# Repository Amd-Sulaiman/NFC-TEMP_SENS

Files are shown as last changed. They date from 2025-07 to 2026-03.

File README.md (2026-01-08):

# NFC-TEMP_SENS
Gen 1 prototype of a contact-based temperature screening system using ESP32-C6 and NFC. Measures body temperature via Medical grade TMP117, stores data on an ST25DV64KC NFC tag, and supports smartphone tap-to-read + cloud sync for patient analytics.
# NFC-Based Smart Temperature Logger (Gen 1)

Gen-1 prototype: **ESP32-C6 Mini** + **TMP117** for contact body temperature, stores session data on **ST25DV64KC NFC tag** (tap with a smartphone to view) and can **send data to a server** for analysis. Each session records **12 readings in ~1 minute**, classifies **Normal / Fever / High Fever**, and saves a compact NDEF text payload to the NFC tag.

## ✨ Features
- Medical-grade temp sensor: **TMP117**
- NFC tag with dynamic memory: **ST25DV64KC**
- **ESP32-C6 Mini** (Wi-Fi + BT)
- **12 readings**/session (5s interval, ~60s total)
- Tap **smartphone → see temp + status**
- **HTTP POST** to server with session data
- **Patient ID** support (basic placeholder)

## 🧰 Hardware
| Part | Notes |
|---|---|
| ESP32-C6 Mini | 3.3V, I²C (SDA/SCL), Wi-Fi |
| TMP117 | I²C 0x48 (default), ±0.1°C typical |
| ST25DV64KC | NFC/RFID dynamic tag, I²C 0x53 |
| Finger contact | Ensure consistent placement/pressure |

## 📸 Prototype Gallery 

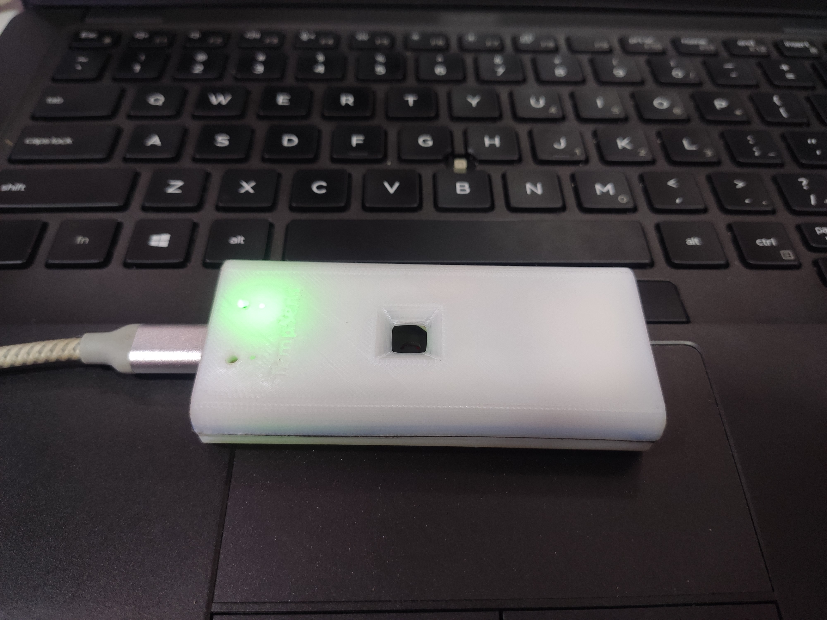
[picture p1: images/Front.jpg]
Prototype — Front

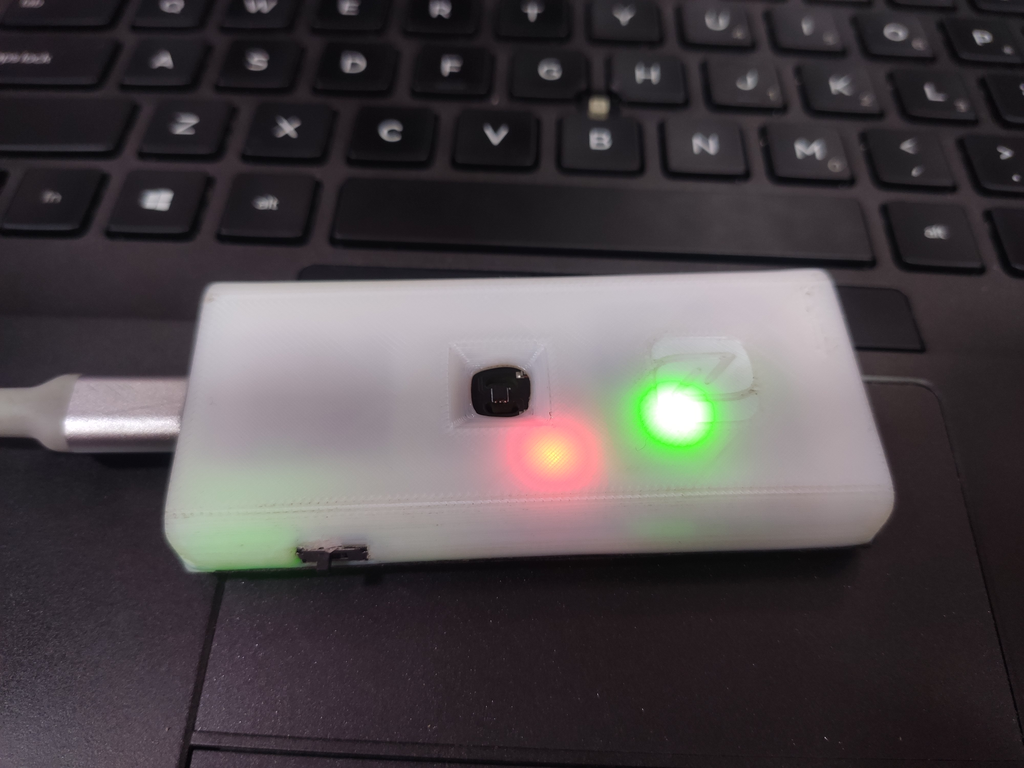
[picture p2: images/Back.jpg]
Prototype — Back

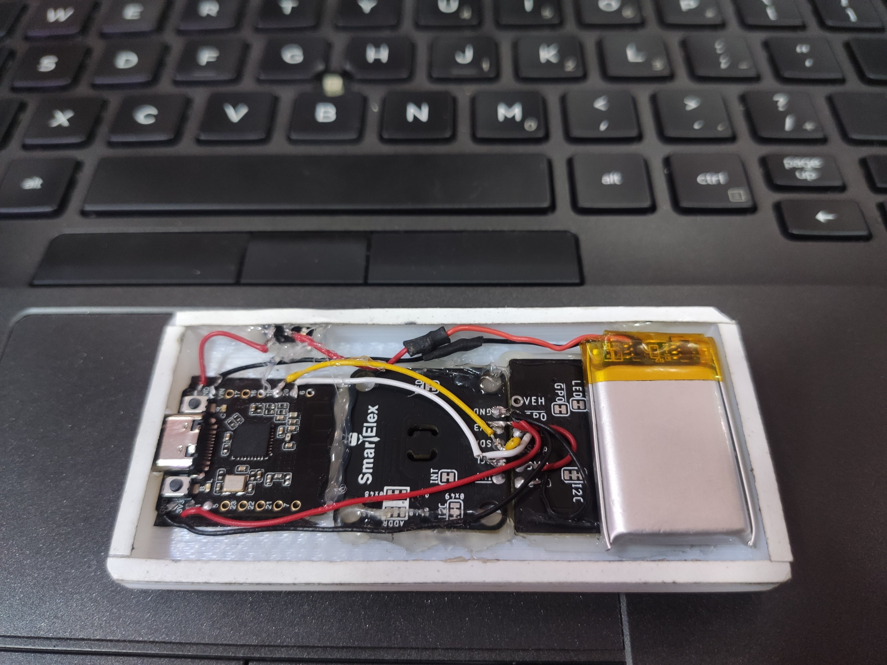
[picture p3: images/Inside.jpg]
Sensor Close-up


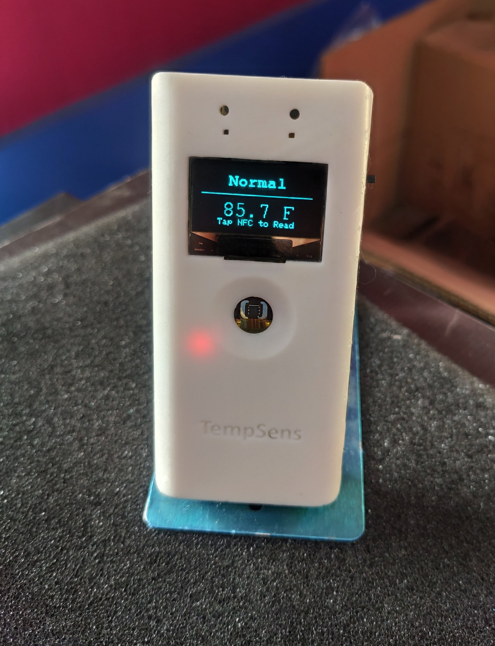
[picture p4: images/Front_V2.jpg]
Version2 — Front

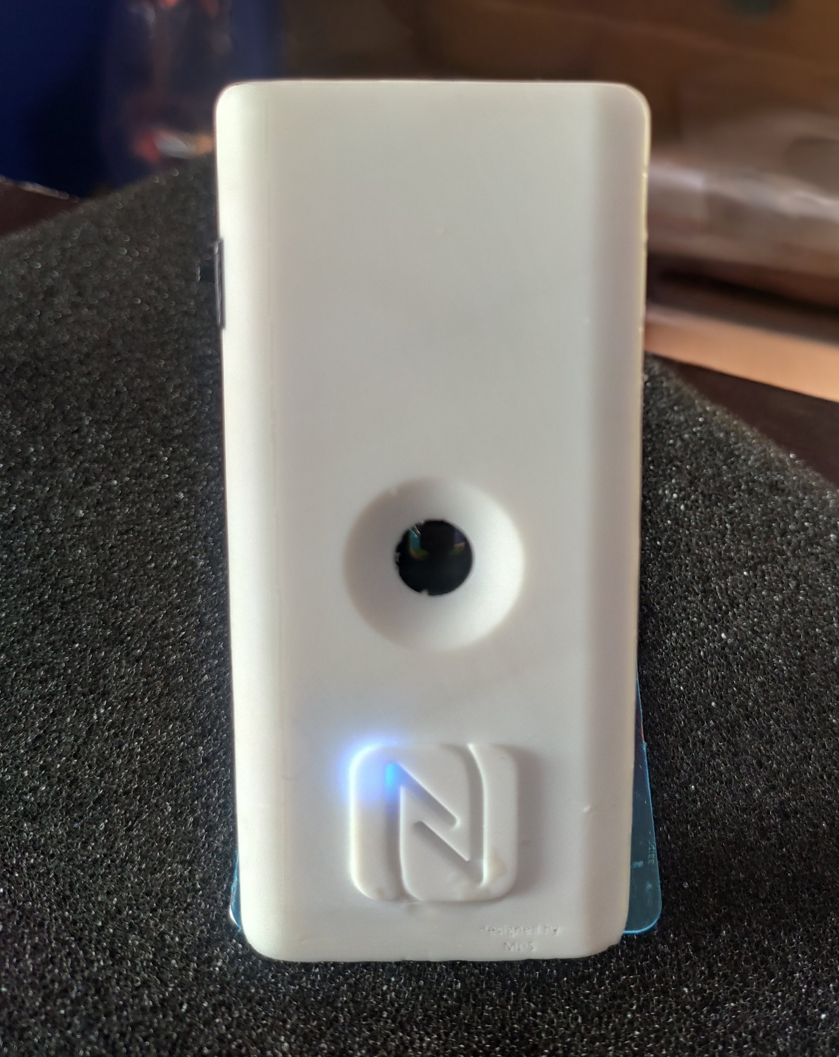
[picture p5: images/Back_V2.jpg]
Version2 — Back

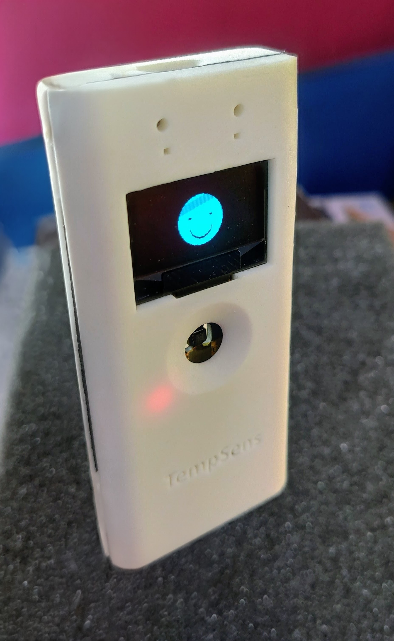
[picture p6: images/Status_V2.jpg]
Version2 — Status Page

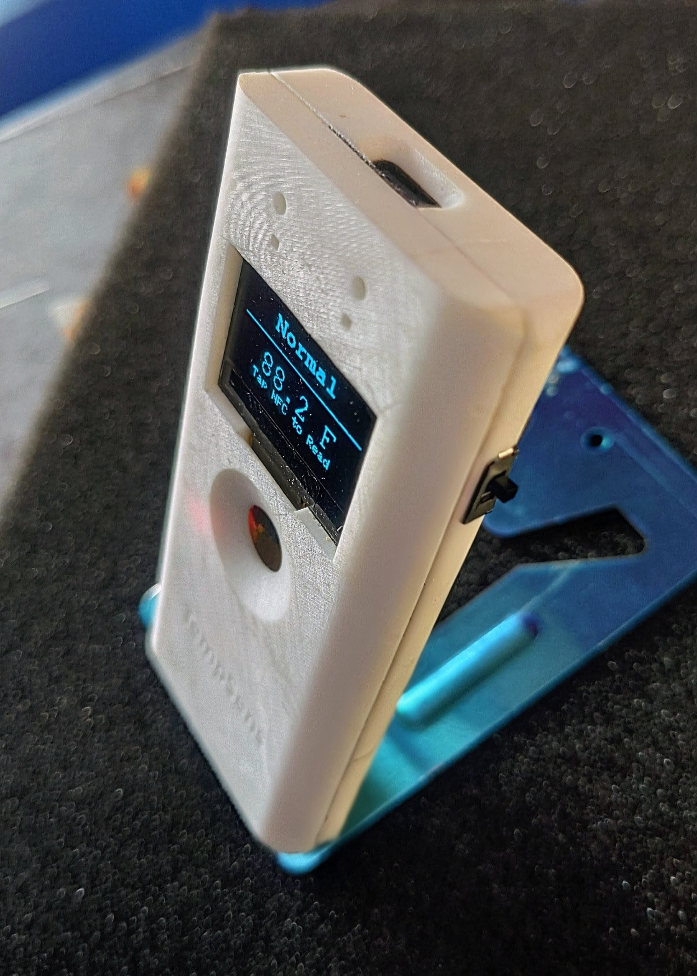
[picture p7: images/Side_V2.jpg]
Version2 — Side
.

## 🧱 3D Model & Enclosure

- [Enclosure Bottom (STL)](3D%20Model/SENS_enclosure_bottom.stl)
- [Enclosure top (STL)](3D%20Model/SENS_enclosure_top.stl)

## 🚦 Status thresholds (default)
- **Normal**: `< 37.5°C` (99.5°F)
- **Fever**: `≥ 37.5°C and < 38.9°C` (102.0°F)
- **High Fever**: `≥ 38.9°C`

> You can adjust these in `firmware/include/config.h`.

## 🔌 Firmware
- Arduino-style C++ (works in Arduino IDE or PlatformIO)
- I²C: TMP117 + ST25DV64KC
- Writes **NDEF Text** record: e.g. `T=37.8C; S=Fever; N=12; ts=2025-08-18T12:03:21Z; pid=abc123`

### Quick start (Arduino IDE)
1. Install **ESP32 boards** (Board Manager).
2. Open `firmware/src/main.cpp`.
3. Copy `firmware/include/secrets.h.example` → `secrets.h` and fill Wi-Fi + server.
4. Select your ESP32-C6 board, compile & upload.
5. Open Serial Monitor @ 115200.

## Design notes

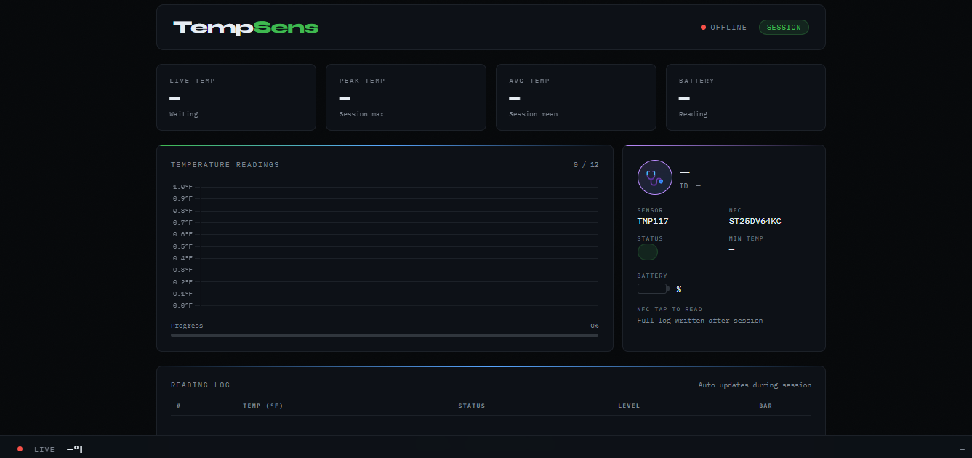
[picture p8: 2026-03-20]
images/dashboard.png

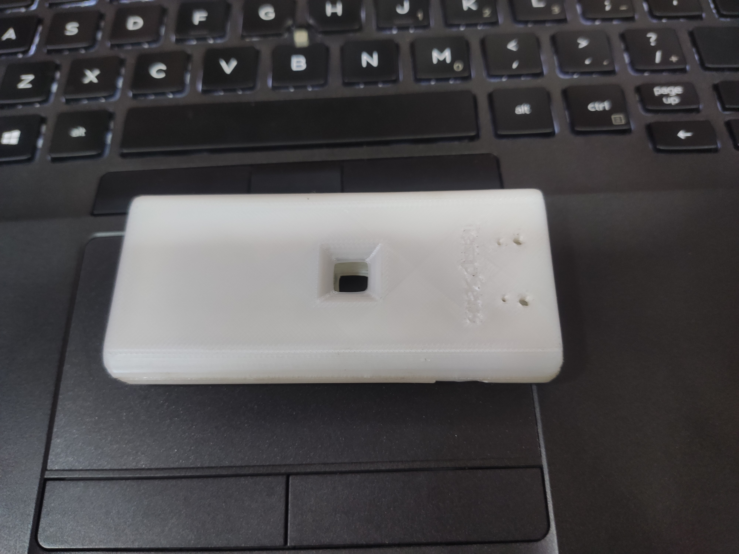
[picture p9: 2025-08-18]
images/Case.jpg

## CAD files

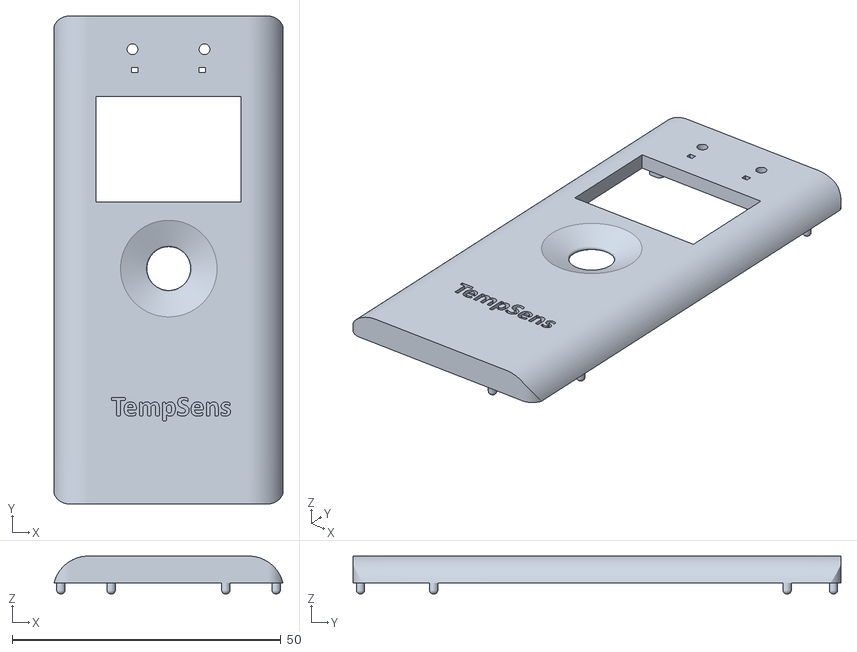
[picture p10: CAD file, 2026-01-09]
3D Model/Lid_V2.stl
42.6 x 90.8 x 7.05

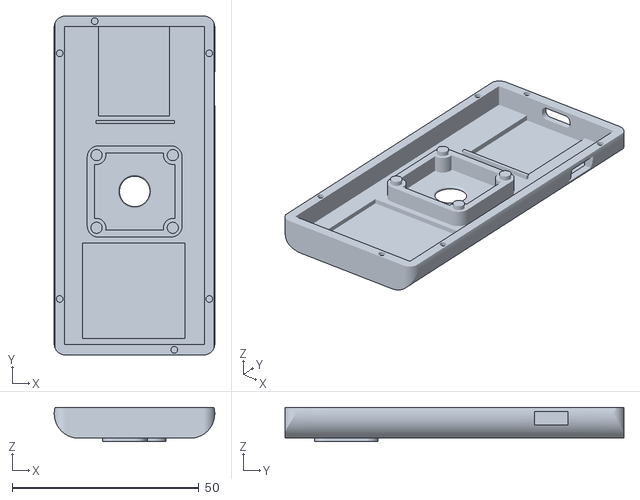
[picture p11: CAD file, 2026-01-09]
3D Model/Body_V2.stl
43.0 x 90.8 x 9.15

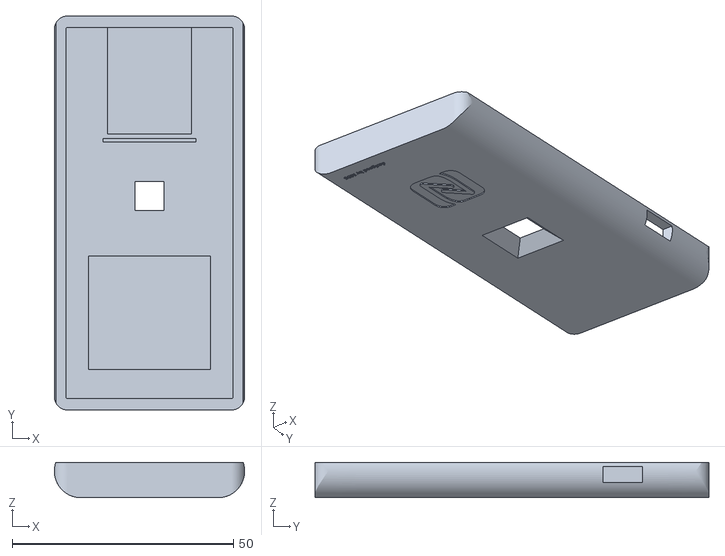
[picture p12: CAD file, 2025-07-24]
3D Model/SENS_enclosure_bottom.stl
43.0 x 89.0 x 8.00

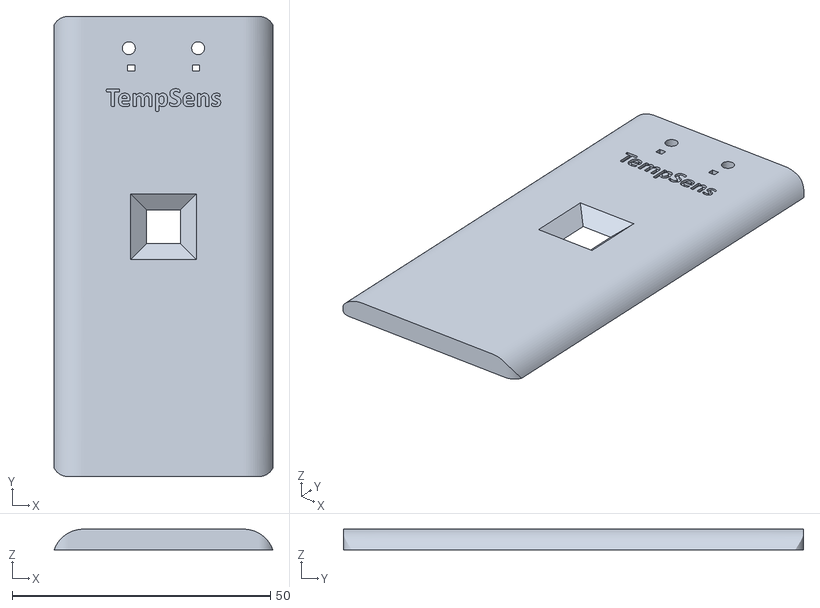
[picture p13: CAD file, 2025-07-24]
3D Model/SENS_enclosure_top.stl
42.3 x 89.0 x 4.00

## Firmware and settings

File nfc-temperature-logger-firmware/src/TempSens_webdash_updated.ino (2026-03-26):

/*
 * TempSens v5 — Cold Chain & Patient Monitor
 * ============================================
 * Hardware: ESP32, TMP117, ST25DV64KC (64Kbit = 8192 bytes), SSD1306 OLED
 *
 * ST25DV64KC MEMORY MAP:
 *   Total EEPROM : 8192 bytes
 *   Target usage : 70-80% = ~5734-6553 bytes
 *   NFC_LOG_MAX  : 5800 bytes (70.8%) — safe headroom
 *   CC File      : 8 bytes (managed by library)
 *   NDEF overhead: ~12 bytes per record
 *
 * KEY FEATURES:
 *   - NFC: meaningful alerts only (fever/high/sudden change/low) with \r\n
 *   - WiFi: continuous reading until power-off (no session limit)
 *   - WiFi: STA mode preferred; AP fallback; resets to STA-first on reboot
 *   - AP/STA SSID+Password configurable from web dashboard
 *   - OLED + WiFi update simultaneously (non-blocking millis() architecture)
 *   - Timestamps from browser JS injected via /api/sync
 *   - Anomaly detection: sustained high, sudden spike, sudden drop, sustained low
 *   - NFC writes top meaningful events only (not every reading)
 *   - Configurable: reading interval, NFC entry count, thresholds
 *
 * SETUP:
 *   1. Flash — open Serial at 115200
 *   2. On first boot with no saved WiFi: connects as AP "TempSens-Setup"
 *   3. Open 192.168.4.1 → Settings tab → enter your WiFi credentials → Save
 *   4. Device reboots into STA mode
 *   5. On subsequent boots: always tries STA first, AP only if STA fails after timeout
 */

#include <Wire.h>
#include <Adafruit_GFX.h>
#include <Adafruit_SSD1306.h>
#include <Fonts/FreeMono12pt7b.h>
#include <Fonts/FreeMonoBold9pt7b.h>
#include <SparkFun_ST25DV64KC_Arduino_Library.h>
#include <SparkFun_TMP117.h>
#include <WiFi.h>
#include <WebServer.h>
#include <ArduinoJson.h>
#include <Preferences.h>      // NVS — persist WiFi creds + config

// =====================================================
// HARDWARE
// =====================================================
#define SCREEN_WIDTH   128
#define SCREEN_HEIGHT   64
#define OLED_RESET      -1
#define BATTERY_PIN      1

Adafruit_SSD1306 display(SCREEN_WIDTH, SCREEN_HEIGHT, &Wire, OLED_RESET);
SFE_ST25DV64KC_NDEF tag;
TMP117 tempSensor;
WebServer server(80);
Preferences prefs;

// =====================================================
// NFC MEMORY BUDGET
// ST25DV64KC = 8192 bytes total EEPROM
// We target 70-80% = ~5734-6553 bytes
// NFC_LOG_MAX = 5800 bytes (70.8% of 8192)
// Each meaningful event line ≈ 60 bytes with \r\n
// So we can store ~90 meaningful events comfortably
// =====================================================
#define NFC_TOTAL_BYTES    8192
#define NFC_LOG_MAX        5800   // 70.8% of 8192 — target 70-80%
#define NFC_MAX_EVENTS      90    // max meaningful events stored on NFC

// =====================================================
// DEFAULT ADJUSTABLE PARAMETERS (saved to NVS, editable via web)
// =====================================================
#define DEFAULT_READING_INTERVAL_SEC  10
#define DEFAULT_NFC_STORE_EVERY_N      4   // store 1 in N normal readings on NFC
#define DEFAULT_TEMP_LOW              95.0  // F — below this = cold alert
#define DEFAULT_TEMP_ELEVATED         99.0  // F
#define DEFAULT_TEMP_FEVER           100.4  // F
#define DEFAULT_TEMP_HIGH_FEVER      102.4  // F
#define DEFAULT_SPIKE_THRESHOLD        1.5  // F change in one reading = spike
#define DEFAULT_NUM_NFC_READINGS       60   // max readings stored on NFC

// WiFi
#define AP_SSID_DEFAULT   "TempSens-Setup"
#define AP_PASSWORD       "tempsens123"
#define STA_CONNECT_TIMEOUT_MS  15000
#define WIFI_RETRY_INTERVAL_SEC    60

// OLED
#define OLED_TRANSITION_MS  400

// =====================================================
// RUNTIME CONFIG (loaded from NVS on boot)
// =====================================================
struct Config {
  char    staSSID[64];
  char    staPass[64];
  char    apSSID[32];
  char    patientName[32];
  char    patientID[16];
  char    monitorMode[16];  // "patient" or "coldchain"
  int     readingIntervalSec;
  int     nfcStoreEveryN;
  int     numNfcReadings;
  float   tempLow;
  float   tempElevated;
  float   tempFever;
  float   tempHighFever;
  float   spikeThreshold;
} cfg;

void loadConfig() {
  prefs.begin("tempsens", true);
  strlcpy(cfg.staSSID,          prefs.getString("ssid",    "").c_str(),          sizeof(cfg.staSSID));
  strlcpy(cfg.staPass,          prefs.getString("pass",    "").c_str(),          sizeof(cfg.staPass));
  strlcpy(cfg.apSSID,           prefs.getString("apssid",  AP_SSID_DEFAULT).c_str(), sizeof(cfg.apSSID));
  strlcpy(cfg.patientName,      prefs.getString("pname",   "Unknown").c_str(),   sizeof(cfg.patientName));
  strlcpy(cfg.patientID,        prefs.getString("pid",     "000").c_str(),       sizeof(cfg.patientID));
  strlcpy(cfg.monitorMode,      prefs.getString("mode",    "patient").c_str(),   sizeof(cfg.monitorMode));
  cfg.readingIntervalSec = prefs.getInt("interval",  DEFAULT_READING_INTERVAL_SEC);
  cfg.nfcStoreEveryN     = prefs.getInt("nfcevery",  DEFAULT_NFC_STORE_EVERY_N);
  cfg.numNfcReadings     = prefs.getInt("nfccount",  DEFAULT_NUM_NFC_READINGS);
  cfg.tempLow            = prefs.getFloat("tlow",    DEFAULT_TEMP_LOW);
  cfg.tempElevated       = prefs.getFloat("televated", DEFAULT_TEMP_ELEVATED);
  cfg.tempFever          = prefs.getFloat("tfever",  DEFAULT_TEMP_FEVER);
  cfg.tempHighFever      = prefs.getFloat("thigh",   DEFAULT_TEMP_HIGH_FEVER);
  cfg.spikeThreshold     = prefs.getFloat("tspike",  DEFAULT_SPIKE_THRESHOLD);
  prefs.end();
}

void saveConfig() {
  prefs.begin("tempsens", false);
  prefs.putString("ssid",      cfg.staSSID);
  prefs.putString("pass",      cfg.staPass);
  prefs.putString("apssid",    cfg.apSSID);
  prefs.putString("pname",     cfg.patientName);
  prefs.putString("pid",       cfg.patientID);
  prefs.putString("mode",      cfg.monitorMode);
  prefs.putInt("interval",     cfg.readingIntervalSec);
  prefs.putInt("nfcevery",     cfg.nfcStoreEveryN);
  prefs.putInt("nfccount",     cfg.numNfcReadings);
  prefs.putFloat("tlow",       cfg.tempLow);
  prefs.putFloat("televated",  cfg.tempElevated);
  prefs.putFloat("tfever",     cfg.tempFever);
  prefs.putFloat("thigh",      cfg.tempHighFever);
  prefs.putFloat("tspike",     cfg.spikeThreshold);
  prefs.end();
}

// =====================================================
// READING STORAGE (continuous — WiFi logs everything)
// Dynamic allocation capped at 2048 readings ~= plenty
// =====================================================
#define MAX_WIFI_READINGS  2048

struct Reading {
  float   tempF;
  uint32_t localMs;       // millis() at time of reading
  char    browserTime[24]; // "HH:MM:SS" from browser sync
  uint8_t flags;          // bitmask: 0x01=spike_up 0x02=spike_down 0x04=low 0x08=elevated 0x10=fever 0x20=high_fever
};

Reading  readings[MAX_WIFI_READINGS];
int      readingCount    = 0;
float    maxTemp         = -999.0;
float    minTemp         =  999.0;
float    latestTemp      =  98.6;
bool     sessionStarted  = false;

// NFC event log (only meaningful events)
struct NfcEvent {
  int     index;
  float   tempF;
  uint8_t flags;
  char    browserTime[24];
  float   change;
};
NfcEvent nfcEvents[NFC_MAX_EVENTS];
int      nfcEventCount   = 0;

// =====================================================
// WIFI / NETWORK STATE
// =====================================================
bool         wifiConnected    = false;
bool         apModeActive     = false;
unsigned long lastWifiRetryMs = 0;
unsigned long sessionStartMs  = 0;
unsigned long lastReadingMs   = 0;

// Browser time sync — offset between browser epoch and millis()
// browserEpochMs = millis() at moment of sync + browserTimeAtSync
bool          timeSynced        = false;
unsigned long syncMillis        = 0;
unsigned long long browserEpochAtSync = 0; // ms

// Current session status string
const char*  sessionStatus = "Waiting";

// =====================================================
// UTILITIES
// =====================================================

void printCentered(const char* text, int y, const GFXfont* font = NULL) {
  int16_t x1, y1; uint16_t w, h;
  if (font) display.setFont(font); else display.setFont();
  display.getTextBounds(text, 0, 0, &x1, &y1, &w, &h);
  int x = (SCREEN_WIDTH - w) / 2;
  if (font) display.setCursor(x, y + h); else display.setCursor(x, y);
  display.print(text);
}

float readBatteryVoltage() {
  long sum = 0;
  for (int i = 0; i < 16; i++) { sum += analogReadMilliVolts(BATTERY_PIN); delay(2); }
  return (sum / 16.0 * 2.0) / 1000.0;
}

int batteryPercentage(float v) {
  if (v >= 4.20) return 100;
  if (v <= 3.30) return 0;
  return constrain((int)(((v - 3.30) / (4.20 - 3.30)) * 100.0), 0, 100);
}

const char* classifyTemp(float f) {
  if (f < cfg.tempLow)         return "Low";
  if (f >= cfg.tempHighFever)  return "High Fever";
  if (f >= cfg.tempFever)      return "Fever";
  if (f >= cfg.tempElevated)   return "Elevated";
  return "Normal";
}

// Build flag bitmask for a reading
uint8_t buildFlags(float f, float prevF, bool isFirst) {
  uint8_t fl = 0;
  if (f < cfg.tempLow)                                  fl |= 0x04; // low
  if (f >= cfg.tempElevated && f < cfg.tempFever)       fl |= 0x08; // elevated
  if (f >= cfg.tempFever    && f < cfg.tempHighFever)   fl |= 0x10; // fever
  if (f >= cfg.tempHighFever)                           fl |= 0x20; // high fever
  if (!isFirst) {
    float diff = f - prevF;
    if (diff  >=  cfg.spikeThreshold) fl |= 0x01; // spike up
    if (diff  <= -cfg.spikeThreshold) fl |= 0x02; // spike down
  }
  return fl;
}

bool isMeaningful(uint8_t flags) {
  return flags != 0; // any flag = meaningful
}

// Get browser time string for a reading (uses sync offset)
void getBrowserTime(char* buf, size_t len, uint32_t readingMs) {
  if (!timeSynced) {
    snprintf(buf, len, "--:--:--");
    return;
  }
  unsigned long long epochMs = browserEpochAtSync + (readingMs - syncMillis);
  unsigned long epochSec = (unsigned long)(epochMs / 1000);
  int hh = (epochSec / 3600) % 24;
  int mm = (epochSec /   60) % 60;
  int ss =  epochSec         % 60;
  snprintf(buf, len, "%02d:%02d:%02d", hh, mm, ss);
}

// =====================================================
// OLED SCREENS
// =====================================================

void oledClear() {
  display.clearDisplay();
  display.display();
  delay(OLED_TRANSITION_MS);
}

void showWelcomeScreen() {
  oledClear();
  display.setTextColor(SSD1306_WHITE);
  printCentered("TempSens", 14, &FreeMono12pt7b);
  printCentered("v5", 36, NULL);
  display.drawRect(10, 48, 108, 6, SSD1306_WHITE);
  display.fillRect(12, 50, 104, 2, SSD1306_WHITE);
  display.display();
  delay(1500);
}

void showWiFiStatus(bool connected, const char* ip, bool isSTA) {
  oledClear();
  display.setFont(); display.setTextSize(1);
  if (connected && isSTA) {
    printCentered("WiFi Connected", 2, NULL);
    printCentered(ip, 20, NULL);
    printCentered("Open browser:", 36, NULL);
    printCentered(ip, 48, NULL);
  } else {
    printCentered("AP Mode", 2, NULL);
    printCentered(cfg.apSSID, 16, NULL);
    printCentered("pw:tempsens123", 30, NULL);
    printCentered("192.168.4.1", 46, NULL);
  }
  display.display();
  delay(3000);
}

void showReadingScreen(float fval, int idx, uint8_t flags) {
  // Temp value — top region
  display.fillRect(0, 0, 128, 30, SSD1306_BLACK);
  display.setFont(&FreeMono12pt7b);
  display.setTextColor(SSD1306_WHITE);
  char ts[14]; snprintf(ts, sizeof(ts), "%.1fF", fval);
  printCentered(ts, 2, &FreeMono12pt7b);

  // Status + flags
  display.setFont();
  display.fillRect(0, 32, 128, 9, SSD1306_BLACK);
  const char* cls = classifyTemp(fval);
  char statusLine[32];
  if      (flags & 0x01) snprintf(statusLine, sizeof(statusLine), "%s ^SPIKE", cls);
  else if (flags & 0x02) snprintf(statusLine, sizeof(statusLine), "%s vDROP",  cls);
  else                   snprintf(statusLine, sizeof(statusLine), "%s",         cls);
  printCentered(statusLine, 32, NULL);

  // Counter + elapsed
  display.fillRect(0, 44, 128, 8, SSD1306_BLACK);
  char lbl[28];
  int elapsed = (int)((millis() - sessionStartMs) / 1000);
  int em = elapsed / 60, es = elapsed % 60;
  snprintf(lbl, sizeof(lbl), "R%d | %02d:%02d", idx+1, em, es);
  printCentered(lbl, 44, NULL);

  // Alert bar if anomalous
  display.fillRect(0, 56, 128, 8, SSD1306_BLACK);
  if (flags) {
    display.fillRect(0, 56, 128, 8, SSD1306_WHITE);
    display.setTextColor(SSD1306_BLACK);
    if      (flags & 0x20) printCentered("!! HIGH FEVER !!", 57, NULL);
    else if (flags & 0x10) printCentered("! FEVER ALERT !", 57, NULL);
    else if (flags & 0x04) printCentered("! LOW TEMP !", 57, NULL);
    else if (flags & 0x01) printCentered("^ SUDDEN RISE ^", 57, NULL);
    else if (flags & 0x02) printCentered("v SUDDEN DROP v", 57, NULL);
    else                   printCentered("~ ELEVATED ~", 57, NULL);
    display.setTextColor(SSD1306_WHITE);
  } else {
    printCentered("Normal", 57, NULL);
  }

  display.display();
  // No delay — non-blocking
}

void showFinalScreen(float mxTemp) {
  oledClear();
  display.setFont(&FreeMonoBold9pt7b);
  printCentered(sessionStatus, 5, &FreeMonoBold9pt7b);
  display.drawLine(0, 26, 128, 26, SSD1306_WHITE);
  display.setFont(&FreeMono12pt7b);
  char buf[16]; snprintf(buf, sizeof(buf), "%.1fF", mxTemp);
  printCentered(buf, 32, &FreeMono12pt7b);
  display.setFont();
  char aline[28];
  snprintf(aline, sizeof(aline), "Events: %d R:%d", nfcEventCount, readingCount);
  printCentered(aline, 54, NULL);
  display.display();
}

// =====================================================
// NFC LOG BUILDER
// Only writes meaningful events — fills up to NFC_LOG_MAX
// Uses \r\n for universal phone reader compatibility
// =====================================================
char nfcLogBuf[NFC_LOG_MAX + 64]; // slight oversize for safety check
uint16_t nfcMemLoc = 0;

void buildAndWriteNFC() {
  memset(nfcLogBuf, 0, sizeof(nfcLogBuf));
  size_t used = 0;
  size_t budget = NFC_LOG_MAX;

  // === HEADER ===
  char hdr[160];
  float avg = 0;
  for (int i = 0; i < readingCount; i++) avg += readings[i].tempF;
  if (readingCount > 0) avg /= readingCount;

  int elapsed = (int)((millis() - sessionStartMs) / 1000);
  int em = elapsed/60, es = elapsed%60;

  snprintf(hdr, sizeof(hdr),
    "TempSens v5\r\n"
    "Mode:%s\r\n"
    "Pt:%s ID:%s\r\n"
    "Max:%.2fF Min:%.2fF Avg:%.2fF\r\n"
    "Status:%s Events:%d\r\n"
    "Duration:%02d:%02d Readings:%d\r\n"
    "-- EVENTS (Meaningful Only) --\r\n",
    cfg.monitorMode,
    cfg.patientName, cfg.patientID,
    maxTemp, minTemp, avg,
    sessionStatus, nfcEventCount,
    em, es, readingCount);

  size_t hlen = strlen(hdr);
  if (hlen < budget) {
    memcpy(nfcLogBuf, hdr, hlen);
    used = hlen;
  }

  // === MEANINGFUL EVENTS ===
  int written = 0;
  for (int i = 0; i < nfcEventCount && used < budget - 80; i++) {
    NfcEvent& e = nfcEvents[i];
    char tag_str[48] = "";

    // Build human-readable flag tags
    if      (e.flags & 0x20) strlcat(tag_str, "[HIGH-FEVER]",   sizeof(tag_str));
    else if (e.flags & 0x10) strlcat(tag_str, "[FEVER]",        sizeof(tag_str));
    else if (e.flags & 0x08) strlcat(tag_str, "[ELEVATED]",     sizeof(tag_str));
    else if (e.flags & 0x04) strlcat(tag_str, "[LOW]",          sizeof(tag_str));
    if      (e.flags & 0x01) strlcat(tag_str, "[SPIKE+]",       sizeof(tag_str));
    if      (e.flags & 0x02) strlcat(tag_str, "[DROP-]",        sizeof(tag_str));

    char chgStr[12];
    if (e.change >= 0) snprintf(chgStr, sizeof(chgStr), "+%.2fF", e.change);
    else               snprintf(chgStr, sizeof(chgStr), "%.2fF",  e.change);

    char line[96];
    snprintf(line, sizeof(line),
      "R%03d %s %.2fF %s chg:%s\r\n",
      e.index, e.browserTime, e.tempF, tag_str, chgStr);

    size_t llen = strlen(line);
    if (used + llen < budget) {
      memcpy(nfcLogBuf + used, line, llen);
      used += llen;
      written++;
    } else break;
  }

  // === FOOTER ===
  char foot[80];
  snprintf(foot, sizeof(foot),
    "-- END %d/%d events written --\r\n"
    "NFC used:%d/%d bytes (%.0f%%)\r\n",
    written, nfcEventCount,
    (int)used, NFC_TOTAL_BYTES,
    (float)used / NFC_TOTAL_BYTES * 100.0);

  size_t flen = strlen(foot);
  if (used + flen < budget) {
    memcpy(nfcLogBuf + used, foot, flen);
    used += flen;
  }

  Serial.printf("NFC log: %d bytes / %d budget (%.1f%% of tag)\n",
    (int)used, NFC_LOG_MAX,
    (float)used / NFC_TOTAL_BYTES * 100.0);

  // Write to tag
  nfcMemLoc = tag.getCCFileLen();
  tag.writeNDEFText(nfcLogBuf, &nfcMemLoc, true, true);
  Serial.printf("NFC written: %d events, %d bytes\n", written, (int)used);
}

// =====================================================
// WEB SERVER — API HANDLERS
// =====================================================

void handleApiSync() {
  // Browser posts its current epoch ms so we can timestamp readings
  server.sendHeader("Access-Control-Allow-Origin", "*");
  if (server.method() == HTTP_POST && server.hasArg("plain")) {
    StaticJsonDocument<128> doc;
    if (!deserializeJson(doc, server.arg("plain"))) {
      unsigned long long epochMs = doc["epochMs"].as<unsigned long long>();
      syncMillis          = millis();
      browserEpochAtSync  = epochMs;
      timeSynced          = true;
      // Backfill timestamps for readings taken before sync
      for (int i = 0; i < readingCount; i++) {
        if (readings[i].browserTime[0] == '-') {
          getBrowserTime(readings[i].browserTime,
            sizeof(readings[i].browserTime),
            readings[i].localMs);
        }
      }
      server.send(200, "application/json", "{\"ok\":true}");
      return;
    }
  }
  server.send(400, "application/json", "{\"ok\":false}");
}
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
void loop() {
  server.handleClient();

  // === STA retry (if in AP fallback mode) ===
  if (apModeActive && !wifiConnected) {
    unsigned long now2 = millis();
    if (now2 - lastWifiRetryMs > (unsigned long)(WIFI_RETRY_INTERVAL_SEC * 1000UL)) {
      lastWifiRetryMs = now2;
      Serial.println("Retrying STA...");
      server.stop();
      WiFi.mode(WIFI_OFF); delay(100);
      WiFi.mode(WIFI_STA);
      WiFi.begin(cfg.staSSID, cfg.staPass);
      unsigned long rs = millis();
      while (WiFi.status() != WL_CONNECTED && millis() - rs < 10000) {
        server.handleClient(); // keep AP clients served during retry window
        delay(100);
      }
      if (WiFi.status() == WL_CONNECTED) {
        wifiConnected = true; apModeActive = false;
        server.begin();
        Serial.println("STA reconnected: " + WiFi.localIP().toString());
        // Show on OLED briefly but don't block readings
        display.fillRect(0, 56, 128, 8, SSD1306_BLACK);
        display.setFont(); display.setTextColor(SSD1306_WHITE);
        char ipBuf[20]; WiFi.localIP().toString().toCharArray(ipBuf, sizeof(ipBuf));
        printCentered(ipBuf, 57, NULL);
        display.display();
      } else {
        // Restore AP — server still works for connected clients
        WiFi.mode(WIFI_AP);
        WiFi.softAP(cfg.apSSID, AP_PASSWORD);
        delay(100);
        server.begin();
        Serial.println("STA retry failed, AP restored");
      }
    }
  }

  if (!sessionStarted) return;

  // === Non-blocking reading timer ===
  unsigned long now = millis();
  if (now - lastReadingMs < (unsigned long)(cfg.readingIntervalSec * 1000UL)) return;
  lastReadingMs = now;

  // Sensor sanity check
  float c = tempSensor.readTempC();
  if (c < 20.0 || c > 50.0) {
    Serial.printf("Sensor read suspect (%.2fC) — skipped\n", c);
    return;
  }
  float f = c * 9.0 / 5.0 + 32.0;

  if (readingCount >= MAX_WIFI_READINGS) {
    // Rotate: drop oldest, shift down
    memmove(&readings[0], &readings[1], (MAX_WIFI_READINGS - 1) * sizeof(Reading));
    readingCount = MAX_WIFI_READINGS - 1;
  }

  float prevF = readingCount > 0 ? readings[readingCount-1].tempF : f;
  uint8_t flags = buildFlags(f, prevF, readingCount == 0);

  readings[readingCount].tempF   = f;
  readings[readingCount].localMs = now;
  readings[readingCount].flags   = flags;
  getBrowserTime(readings[readingCount].browserTime,
    sizeof(readings[readingCount].browserTime), now);

  latestTemp = f;
  if (f > maxTemp) maxTemp = f;
  if (f < minTemp) minTemp = f;

  // Track NFC-worthy events
  if (isMeaningful(flags) && nfcEventCount < NFC_MAX_EVENTS) {
    nfcEvents[nfcEventCount].index  = readingCount + 1;
    nfcEvents[nfcEventCount].tempF  = f;
    nfcEvents[nfcEventCount].flags  = flags;
    nfcEvents[nfcEventCount].change = f - prevF;
    strlcpy(nfcEvents[nfcEventCount].browserTime,
      readings[readingCount].browserTime, 24);
    nfcEventCount++;
    Serial.printf("EVENT R%d: %.2fF flags=0x%02X\n", readingCount+1, f, flags);
    // Update NFC tag with latest events
    buildAndWriteNFC();
  }

  // Update session status
  if      (maxTemp >= cfg.tempHighFever) sessionStatus = "High Fever";
  else if (maxTemp >= cfg.tempFever)     sessionStatus = "Fever";
  else if (maxTemp >= cfg.tempElevated)  sessionStatus = "Elevated";
  else if (minTemp <  cfg.tempLow)       sessionStatus = "Low Temp";
  else                                   sessionStatus = "Normal";

  readingCount++;

  Serial.printf("R%d: %.2fF [%s] flags=0x%02X t=%s\n",
    readingCount, f, classifyTemp(f), flags, readings[readingCount-1].browserTime);

  // OLED update — non-blocking, no delay
  showReadingScreen(f, readingCount-1, flags);
}

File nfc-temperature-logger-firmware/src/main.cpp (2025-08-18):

//how the code works

//TMP117 driver: minimal I²C read of the temperature register, converting the raw 16-bit value: °C = raw * 0.0078125.

//Session logic: collects READINGS_PER_SESSION samples at SAMPLE_INTERVAL_MS (default 12 × 5s ≈ 60s), computes average, classifies by thresholds in config.h.

//NFC write: builds a single NDEF Text record (ST25DV64KC::writeTextNDEF) and writes it starting at NDEF_START. A smartphone tap shows the compact string.

//Cloud: if Wi-Fi and CLOUD_URL are set, sends one JSON payload per session. Add retries/HTTPS cert pinning later if needed.

//Timestamps: uses SNTP (via configTime) to make an ISO-8601 UTC string.

#include <Arduino.h>
#include <Wire.h>
#include <WiFi.h>
#include <HTTPClient.h>
#include <time.h>

#include "config.h"
#include "secrets.h"     // create from secrets.h.example
#include "ST25DV64KC.h"

// ---------------- TMP117 minimal driver ----------------
static const uint8_t TMP117_REG_TEMP = 0x00;
static const uint8_t TMP117_REG_CONF = 0x01;

bool tmp117_begin() {
  Wire.beginTransmission(TMP117_ADDR);
  Wire.write(TMP117_REG_CONF);
  if (Wire.endTransmission() != 0) return false;
  // Optional: configure averaging etc. (keep defaults)
  return true;
}

// Return temperature in Celsius
bool tmp117_readC(float &outC) {
  Wire.beginTransmission(TMP117_ADDR);
  Wire.write(TMP117_REG_TEMP);
  if (Wire.endTransmission(false) != 0) return false;
  if (Wire.requestFrom((int)TMP117_ADDR, 2) != 2) return false;
  uint16_t raw = ((uint16_t)Wire.read() << 8) | Wire.read();
  // TMP117: 16-bit two's complement, LSB = 7.8125e-3 °C
  int16_t s = (int16_t)raw;
  outC = s * 0.0078125f;
  return true;
}

// --------------- Globals ----------------
ST25DV64KC nfc(Wire);
float readings[READINGS_PER_SESSION];
uint8_t rIndex = 0;

// Simple status classifier
const char* classifyStatus(float c) {
  if (c < THRESH_NORMAL_MAX_C) return "Normal";
  if (c < THRESH_FEVER_MAX_C)  return "Fever";
  return "High Fever";
}

// ISO8601 UTC timestamp via SNTP
String iso8601_utc() {
  time_t now; struct tm tm; char buf[32];
  time(&now);
  gmtime_r(&now, &tm);
  strftime(buf, sizeof(buf), "%Y-%m-%dT%H:%M:%SZ", &tm);
  return String(buf);
}

void connectWiFi() {
  if (strlen(WIFI_SSID) == 0) return; // allow offline
  WiFi.mode(WIFI_MODE_STA);
  WiFi.begin(WIFI_SSID, WIFI_PASSWORD);
  unsigned long start = millis();
  while (WiFi.status() != WL_CONNECTED && millis() - start < 15000) {
    delay(250);
  }
  if (WiFi.status() == WL_CONNECTED) {
    configTime(0, 0, "pool.ntp.org", "time.nist.gov");
  }
}

void sendToCloud(const String& patientId, float avgC, const String& status, const String& isoTs) {
  if (strlen(CLOUD_URL) == 0) return;
  if (WiFi.status() != WL_CONNECTED) return;

  String payload = "{";
  payload += "\"patient_id\":\"" + patientId + "\",";
  payload += "\"timestamp\":\"" + isoTs + "\",";
  payload += "\"readings_c\":[";
  for (int i = 0; i < READINGS_PER_SESSION; ++i) {
    payload += String(readings[i], 3);
    if (i < READINGS_PER_SESSION - 1) payload += ",";
  }
  payload += "],";
  payload += "\"average_c\":" + String(avgC,3) + ",";
  payload += "\"status\":\"" + status + "\",";
  payload += "\"device\":\"" DEVICE_NAME "\",";
  payload += "\"session_count\":" + String(READINGS_PER_SESSION);
  payload += "}";

  HTTPClient http;
  http.begin(CLOUD_URL);
  http.addHeader("Content-Type", "application/json");
  if (strlen(CLOUD_AUTH_BEARER)) {
    http.addHeader("Authorization", String("Bearer ") + CLOUD_AUTH_BEARER);
  }
  int code = http.POST(payload);
  // Optional: check response
  http.end();
}

void writeNFC(float avgC, const String& status, const String& ts, const String& patientId) {
  // Compact text for phone display via NDEF Text record
  // Keep under NFC_TEXT_MAX chars for the demo
  char text[NFC_TEXT_MAX];
  snprintf(text, sizeof(text),
           "T=%.2fC; S=%s; N=%d; ts=%s; pid=%s",
           avgC, status.c_str(), READINGS_PER_SESSION, ts.c_str(), patientId.c_str());
  nfc.writeTextNDEF(text, NDEF_LANG_CODE);
}

void setup() {
  Serial.begin(115200);
  Wire.begin(); // SDA/SCL default pins for your ESP32-C6 board

  Serial.println("[boot] starting...");

  // Sensors
  if (!tmp117_begin()) {
    Serial.println("[tmp117] not found");
  }

  // NFC
  if (!nfc.begin()) {
    Serial.println("[nfc] ST25DV64KC not found or I2C issue");
  }

  // Wi-Fi (optional)
  connectWiFi();
}

void loop() {
  // Take 12 readings every ~5 seconds
  float c;
  if (tmp117_readC(c)) {
    readings[rIndex++] = c;
    Serial.printf("[reading] #%u: %.3f C\n", rIndex, c);
  } else {
    Serial.println("[reading] TMP117 read failed");
  }

  if (rIndex >= READINGS_PER_SESSION) {
    // Compute average
    float sum = 0.f;
    for (int i = 0; i < READINGS_PER_SESSION; ++i) sum += readings[i];
    float avgC = sum / READINGS_PER_SESSION;

    String status = classifyStatus(avgC);
    String ts = iso8601_utc();
    String patientId = DEFAULT_PATIENT_ID;

    Serial.printf("[session] avg=%.3f C, status=%s, ts=%s\n", avgC, status.c_str(), ts.c_str());

    // Write to NFC (phone tap will show text)
    writeNFC(avgC, status, ts, patientId);
    Serial.println("[nfc] NDEF text written");

    // Send to cloud (optional)
    sendToCloud(patientId, avgC, status, ts);
    Serial.println("[cloud] POST attempted");

    // Reset session
    rIndex = 0;
  }

  delay(SAMPLE_INTERVAL_MS);
}

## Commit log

2025-08-18 Create STL
2026-01-08 Add Version 2 images to the prototype gallery
